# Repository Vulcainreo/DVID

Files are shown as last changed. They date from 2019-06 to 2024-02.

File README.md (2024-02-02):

# DVID
Damn Vulnerable IoT Device - The first opensource vulnerable designed IoT device

**⚠️ This project is currently in development ⚠️**

All details are available on DVID website : [http://dvid.eu](http://dvid.eu)

# Project overview

This IoT device is designed by my own and published on OpenSource. The main objective is to provide to each interrested people a vulnerable board to improve their skill in IoT hacking.

The board core is composed by a Atmega328p and a OLED screen. For each vulnerabilities, a firmware could be flashed on the Atmega328p in order to offer a specific vulnerable environment.

There is also connection port like UART, Bluetooth, 2,4Ghz and Wifi. In each vulnerability, a specific extension board must be plugged to the board.

Hacking required attacks tools like USBasp and USBuart.

# Board

You can buy the board on marketplace (available soon) or build it yourself with Gerber files.
The board is shipped with theses three packages :
* **Board only and component reference** : Naked board only. You must buy all component yourself and solder all component.
* **Soldered board without attack component and extention** : Soldered board but you must buy all external tools like USBuart, USBasp, extention board.
* **Full package** : Everything needed (soldered board, external board and attack tools).

# Contribution

If you want to contribute to the project, don't hesitate to open a pull request.
By the way, about firmware compilation, you need to compile for atmega328p breadboard 8mhz.
In order to do that, just add this board to the /arduino/hardware/arduino/avr/board.txt file

```bash
##############################################################

atmega328bb.name=ATmega328 on a breadboard (8 MHz internal clock)

atmega328bb.upload.protocol=arduino
atmega328bb.upload.maximum_size=30720
atmega328bb.upload.speed=57600

atmega328bb.bootloader.low_fuses=0xE2
atmega328bb.bootloader.high_fuses=0xDA
atmega328bb.bootloader.extended_fuses=0x05

atmega328bb.bootloader.file=atmega/ATmegaBOOT_168_atmega328_pro_8MHz.hex
atmega328bb.bootloader.unlock_bits=0x3F
atmega328bb.bootloader.lock_bits=0x0F

atmega328bb.build.mcu=atmega328p
atmega328bb.build.f_cpu=8000000L
atmega328bb.build.core=arduino:arduino
atmega328bb.build.variant=arduino:standard

atmega328bb.bootloader.tool=arduino:avrdude
atmega328bb.upload.tool=arduino:avrdude
```

In order to upload, select "USBAsp" in `Tool -> Programmer` and start the upload using `Sketch -> Upload Using Programmer`

# Write-ups

Many thanks to [@ghozt](https://twitter.com/ghozt), [@shoxxdj](https://twitter.com/shoxxdj) and [@podalirius](https://twitter.com/podalirius)

## In french 🇫🇷

### Hardware

* Find The Datasheet - [https://shoxxdj.fr/dvid-hardware-find-the-datasheet/](https://shoxxdj.fr/dvid-hardware-find-the-datasheet/)
* Find The Datasheet - [https://podalirius.net/fr/writeups/dvid-writeup-01-hardware-find-the-datasheet/](https://podalirius.net/fr/writeups/dvid-writeup-01-hardware-find-the-datasheet/)

### Firmware

* Default Password - [https://shoxxdj.fr/dvid-firmware-defaultpassword/](https://shoxxdj.fr/dvid-firmware-defaultpassword/)
* Default Password - [https://podalirius.net/fr/writeups/dvid-writeup-03-firmware-default-password/](https://podalirius.net/fr/writeups/dvid-writeup-03-firmware-default-password/)

### Bluetooth

* Advertising - [https://podalirius.net/fr/writeups/dvid-writeup-04-bluetooth-advertise/](https://podalirius.net/fr/writeups/dvid-writeup-04-bluetooth-advertise/)
* Characteristics - [https://podalirius.net/fr/writeups/dvid-writeup-05-bluetooth-characteristics/](https://podalirius.net/fr/writeups/dvid-writeup-05-bluetooth-characteristics/)
* Characteristics2 - [https://podalirius.net/fr/writeups/dvid-writeup-06-bluetooth-characteristics2/](https://podalirius.net/fr/writeups/dvid-writeup-06-bluetooth-characteristics2/)

## In english 🇬🇧

### Hardware

* Find The Datasheet - [https://podalirius.net/en/writeups/dvid-writeup-01-hardware-find-the-datasheet/](https://podalirius.net/en/writeups/dvid-writeup-01-hardware-find-the-datasheet)

### Firmware

* Hardcoded Password - [https://podalirius.net/en/writeups/dvid-writeup-02-firmware-hardcoded-password/](https://podalirius.net/en/writeups/dvid-writeup-02-firmware-hardcoded-password/)
* Default Password - [https://podalirius.net/en/writeups/dvid-writeup-03-firmware-default-password/](https://podalirius.net/en/writeups/dvid-writeup-03-firmware-default-password/)

### Bluetooth

* Advertising - [https://podalirius.net/en/writeups/dvid-writeup-04-bluetooth-advertise/](https://podalirius.net/en/writeups/dvid-writeup-04-bluetooth-advertise/)
* Characteristics - [https://podalirius.net/en/writeups/dvid-writeup-05-bluetooth-characteristics/](https://podalirius.net/en/writeups/dvid-writeup-05-bluetooth-characteristics/)
* Characteristics2 - [https://podalirius.net/en/writeups/dvid-writeup-06-bluetooth-characteristics2/](https://podalirius.net/en/writeups/dvid-writeup-06-bluetooth-characteristics2/)

# Part list

Part | Quantity | Total Cost | Buying link
--- | --- | --- | ---
Board | 1 | 3€ | Available soon or build yourself :)
Jumper Double Row Female 2x4P | 2 | 1€ | https://www.banggood.com/30pcs-2_54mm-2x4P-8P-Double-Row-Female-Straight-Pin-Header-Needle-Socket-Pin-Strip-p-1348262.html
Jumper Single Row Male | 4 | 1€ | https://www.banggood.com/10Pcs-40-Pin-2_54mm-Male-Female-SIL-Socket-Row-Strip-PCB-Connector-p-953436.html
28 pins socket (for atmega328p) | 1 | 0,5€ | https://www.banggood.com/50pcs-28-Pins-IC-DIP-2_54mm-Wide-Integrated-Circuit-Sockets-Adaptor-p-1211042.html
Oled Screen 4Pin white | 1 | 5€ | https://www.banggood.com/1_3-Inch-4Pin-White-OLED-LCD-Display-12864-IIC-I2C-Interface-Module-For-Arduino-p-1067874.html
Atmega328p | 1 | 3€ | https://www.banggood.com/DIP28-ATmega328PPU-MCU-IC-Chip-With-Arduino-UNO-Bootloader-p-932159.html
5V to 3V power supply | 1 | 1€ | https://www.banggood.com/5V-To-3_3V-DC-DC-Step-Down-Power-Supply-Buck-Module-AMS1117-800MA-p-933674.html
Status led | 1 | 0,5€ | https://www.banggood.com/10pcs-5mm-3000-6000mcd-LED-Bright-Decoration-Torch-Toy-Light-Green-p-73175.html
Total |  | 15€ |

# Attack tools and extention board

Part | Quantity | Total Cost | Buying link
--- | --- | --- | ---
UsbUART | 1 | 3€ |  https://www.banggood.com/CP2102-USB-To-TTL-Module-p-1263924.html
UsbASP adapter | 1 | 4€ | https://www.banggood.com/3_3V-5V-USBASP-USBISP-AVR-Programmer-Downloader-ATMEGA8-ATMEGA128-With-Download-Cable-p-1179967.html
AT-09 BLE module | 1 | 2€ | https://www.banggood.com/AT-09-4_0-BLE-Wireless-bluetooth-Module-Serial-Port-CC2541-Compatible-HM-10-Module-Connecting-Single-Chip-Microcomputer-p-1455191.html
CSR BLE adapter | 1 | 4€ | https://www.banggood.com/Mini-Wireless-Dongle-CSR-4_0-Bluetooth-Adapter-V4_0-USB-2_03_0-For-Win-7810XP-For-Vista-3264-p-1132661.html
Jumper Wire female female | 1 | 2€ | https://www.banggood.com/120pcs-20cm-Male-To-Female-Female-To-Female-Male-To-Male-Color-Breadboard-Jumper-Cable-Dupont-Wire-Combination-For-Arduino-p-974006.html
ESP8266 | 1 | 2€ | https://www.banggood.com/Upgraded-Version-1M-Flash-ESP8266-ESP-01-WIFI-Transceiver-Wireless-Module-p-979509.html
Total |  | 17€ |

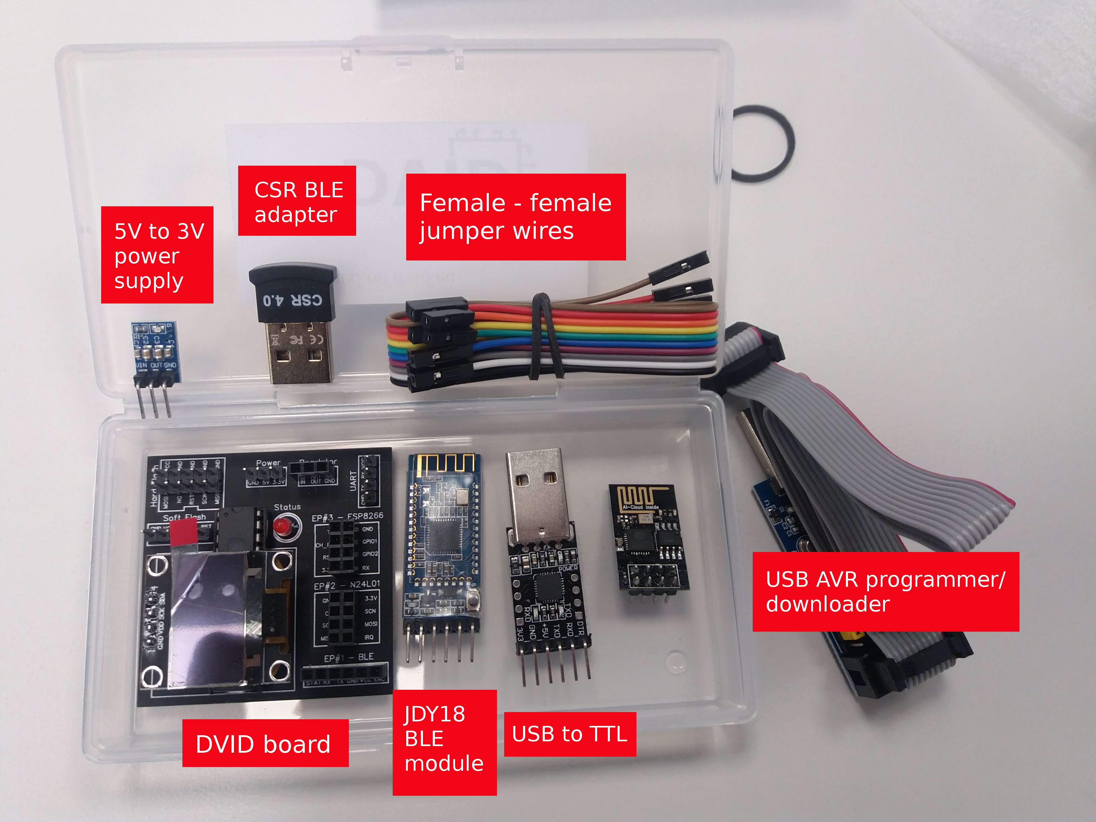
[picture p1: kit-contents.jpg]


# Troubleshooting

In case of frying your board, you may encounter some issue with new version of chinese component. This part is dedicated to allow you to start to discuss with your component and put it in the ready-to-hack configuration

## Bluetooth AT-09

Last received parcel contains a new version of the AT-09, named MLT-BT05. This new version natively discuss over UART with 115200 baudrate.
The DVID can discuss to peripherial with 9600 baudrate.
In order to change that, follow those steps:
* Connect your AT-09 to your uart dongle : RX>TX, TX>RX, VCC>VCC and Gnd>Gnd
* Open a serial monitor and type : AT+BAUD4
* If you receive "OK", your BLE peripherial is ready-to-hack

## Atmega328p

Last received parcel contains a new version of Atmega328p. This version seems to be virgin and allow communication with very slow SCK.
In order to modify the internal configuration (fuse), follow those steps:
* Solder (or shortcut) the Jumper #3 on the USBasp flashing dongle
* Type this command to be sure that you can communicates with the broken Atmega328p : `avrdude -v -patmega328p -cusbasp`
* If you receive "hfuse reads D9" and "lfuse reads FF", your device is already ready-to-hack
* If not, type this command : `avrdude -v -patmega328p -U lfuse:w:0xE2:m -cusbasp`
* You can type again `avrdude -v -patmega328p -cusbasp` to be sure that fuse configuration changed

You can not unsolder or remove shortcut on the Jumper #3. If you don't remove it, flashing process will take 20 more times.
You can now flash all firmware on you DVID !

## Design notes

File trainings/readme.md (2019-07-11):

Here, you will find some training with DVID board.
Please, don't share flags in public.

Have fun :)

# Trainers

You need to flash the firmware on the board.

- Plug USBasp on the board (hard flash zone)
- Plug in any other extension needed for the training e.g the JDY-18 BLE module

Then, flash with `avrdude`:

`avrdude -c usbasp -p m328p -C pathto/avrdude.conf -U flash:w:pathtofirmware.hex`

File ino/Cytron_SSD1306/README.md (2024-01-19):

# Lightweight-I2C-SSD1306

Lightweight I2C SSD1306 Arduino Library for displaying text and simple bitmap images.</br>

<b>Dependencies:</b>
<ul>
<li><a href="https://github.com/greiman/SSD1306Ascii" target=_blank><b>SSD1306Ascii</b> by Greiman</a></li>
</ul>

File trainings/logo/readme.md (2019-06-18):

The following post describes how to use the DVID screen to write text on it 
or to draw pictures on it.

## Arduino IDE and libraries

### IDE
First things first, we will need the Arduino IDE installed.
When this is done we will need to select the proper programmer in 
`Tools > Programmer`. Since we use a USBAsp to program the Atmega328p, we
select **USBAsp**.

### Libraries
Now we will need to install the Adafruit libraries.
To do so, we navigate in **Tools > Manage libraries**.
Then we search for **adafruit SSD1306** and install Adafruit SSD1306.
We then search **adafruit GFX** and install Adafruit GFX Library.

We now have everything needed to start playing with the screen.

## Example sketch

Adafruit provides [examples](https://github.com/adafruit/Adafruit_SSD1306/tree/master/examples) of how to use their library.

We have the choice between four scripts :
- ssd1306_128x32_i2c 	
- ssd1306_128x32_spi 	
- ssd1306_128x64_i2c 	
- ssd1306_128x64_spi

The [OLED screen used by DVID](https://www.banggood.com/1_3-Inch-4Pin-White-OLED-LCD-Display-12864-IIC-I2C-Interface-Module-For-Arduino-p-1067874.html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) has the following characteristics :

- Resolution: 128*64
- Control chip: SSH1106
- Display area: 29.42 x 14.7mm
- Driving voltage: 3.3-5V
- Operating temperature: -40 ℃ to 70 ℃
- Interface type: IIC/I2C  interface

According to our screen characteristics, we use the script `ssd1306_128x64_i2c`.
We copy it in our arduino IDE, and start a compilation (Sketch > Verify/Compile).

Then we upload the sketch to the board with **Sketch > Upload using programmer**.

And ... tada ! *Nothing happens*.

Why is that ?

## I2C address

After [some research](https://startingelectronics.org/tutorials/arduino/modules/OLED-128x64-I2C-display/) we find that the problem lies in this line :
~~~c
 if(!display.begin(SSD1306_SWITCHCAPVCC, 0x3D)) { // Address 0x3D for 128x64
~~~

This bit of code leads us to believe that the parameter `0x3D` is linked to 
the resolution of the screen, but it is not. Actually if we replace `0x3D` 
by `0x3C` as suggested in the blog post linked above, our example will work 
perfectly (in my case, at least).

If we look at the [source code](https://github.com/adafruit/Adafruit_SSD1306/blob/master/Adafruit_SSD1306.cpp) of the Adafruit library we see that the prototype
for the `begin` function is :

~~~c
boolean Adafruit_SSD1306::begin(uint8_t vcs, uint8_t addr, boolean reset,
boolean periphBegin)
~~~

The documentation specifies that 
> @param  addr
       I2C address of corresponding SSD1306 display (or pass 0 to use
       default of 0x3C for 128x32 display, 0x3D for all others).
       SPI displays (hardware or software) do not use addresses, but
       this argument is still required (pass 0 or any value really,
       it will simply be ignored). Default if unspecified is 0.

So `0x3D` is supposed to be the I2C address of the `SSD1306` display.
The issue is the `0x3D` does not seem to be the address of our display.

So how do we find the I2C ? Some quick `DDG` search gives us the tool
[I2cScanner](https://playground.arduino.cc/Main/I2cScanner/
).

So we just have to copy the script into our Arduino IDE and upload it with the 
USBAsp programmer.

Then we use a serial connection to connect to the board and we will get the 
information we are looking for :

~~~bash
cu -l /dev/ttyUSB0 -s 9600
Connected.
Scanning...
I2C device found at address 0x3C  !
done
~~~

Now if we replace the `0x3D` address by the one displayed we will have a working
demo.

## About I2C

We've been talking about I2C but what is it exactly ?

The Inter-integrated Circuit (I2C) Protocol is a protocol intended to allow 
multiple "slave" digital integrated circuits ("chips") to communicate with one 
or more "master" chips. Like the Serial Peripheral Interface (SPI), it is only 
intended for short distance communications within a single device. 
Like Asynchronous Serial Interfaces (such as RS-232 or UARTs), it only requires 
two signal wires to exchange information.

A full introduction can be found on [sparkfun.com](https://learn.sparkfun.com/tutorials/i2c/all).

## Drawing a bitmap

Now that we've seen how to make the example sketch work, let's do one of our 
own.
In this sketch we will attempt to draw a logo from a bitmap.

First we create a logo in Gimp. To do this we create a new project for 
a `128x64` pixels image and we do some pixel art with a hardbrush pencil with 
a size of 1 pixel.

Once this is done we export the logo as a `*.xbm` file.
We then rename the file as `*.c` and open it in an editor.
We retrieve the array and paste it in our sketch.
We just have to [modify the type](https://github.com/adafruit/Adafruit-GFX-Library/pull/31) to `static const uint8_t PROGMEM` then we can use it in our code.

To use it we just have to call `drawXBitmap` and give it our bitmap to display
it.

~~~c
#include <SPI.h>
#include <Wire.h>
#include <Adafruit_GFX.h>
#include <Adafruit_SSD1306.h>
#include <Fonts/FreeSans9pt7b.h>

#define DVID_logo_width 128
#define DVID_logo_height 64

#define SCREEN_WIDTH 128 // OLED display width, in pixels
#define SCREEN_HEIGHT 64 // OLED display height, in pixels

// Declaration for an SSD1306 display connected to I2C (SDA, SCL pins)
#define OLED_RESET     -1 // Reset pin # (or -1 if sharing Arduino reset pin)
Adafruit_SSD1306 display(SCREEN_WIDTH, SCREEN_HEIGHT, &Wire, OLED_RESET);

static const uint8_t PROGMEM DVID_logo_bits[] = {
   0x00, 0x00, 0x00, 0x00, 0x00, 0x00, 0x00, 0x00, 0x00, 0x00, 0x00, 0x00,
   0x00, 0x00, 0x00, 0x00, 0x00, 0x00, 0x00, 0x00, 0x00, 0x00, 0x00, 0x00,
   0x00, 0x1c, 0xfe, 0xff, 0x01, 0x00, 0x00, 0x00, 0x00, 0x00, 0x00, 0x00,
   0x00, 0x00, 0x00, 0x00, 0x00, 0x14, 0x02, 0x00, 0x01, 0x80, 0x03, 0x00,
   0x00, 0x00, 0x00, 0x00, 0x00, 0x00, 0x00, 0x00, 0x00, 0x1c, 0xf2, 0x1f,
   0xff, 0xff, 0x02, 0x00, 0x00, 0x00, 0x00, 0x00, 0x00, 0x00, 0x00, 0x00,
   0x00, 0x08, 0x12, 0x10, 0x00, 0x9c, 0x03, 0x00, 0x00, 0x00, 0x00, 0x00,
   0x00, 0x00, 0x00, 0x00, 0x00, 0x08, 0x12, 0xf0, 0xff, 0x17, 0x00, 0x00,
   0x00, 0x00, 0x00, 0x00, 0x00, 0x00, 0x00, 0x00, 0x00, 0x08, 0x12, 0x00,
   0x00, 0x1c, 0x00, 0x00, 0x00, 0x00, 0x00, 0x00, 0x00, 0x00, 0x00, 0x00,
   0x00, 0x08, 0x12, 0x00, 0x00, 0x00, 0x00, 0x00, 0x00, 0x00, 0x00, 0x00,
   0x00, 0x00, 0x00, 0x00, 0xe0, 0xff, 0xff, 0xff, 0xff, 0x7f, 0x00, 0x00,
   0x00, 0x00, 0x00, 0x00, 0x00, 0x00, 0x00, 0x00, 0x20, 0x00, 0x00, 0x00,
   0x00, 0x40, 0x00, 0x00, 0x00, 0x00, 0x00, 0x00, 0x00, 0x00, 0x00, 0x00,
   0x20, 0x00, 0x00, 0x00, 0x00, 0x40, 0x00, 0x00, 0x00, 0x00, 0x00, 0x00,
   0x00, 0x00, 0x00, 0x00, 0x20, 0x00, 0x00, 0x00, 0x00, 0x40, 0x00, 0x00,
   0x00, 0x00, 0x00, 0x00, 0x00, 0x00, 0x00, 0x00, 0x20, 0x00, 0x00, 0x00,
   0x00, 0x40, 0x00, 0x00, 0x00, 0x00, 0x00, 0x00, 0x00, 0x00, 0x00, 0x00,
   0x20, 0x00, 0x00, 0x00, 0x00, 0x40, 0x00, 0x00, 0x00, 0x00, 0x00, 0x00,
   0x00, 0x00, 0x00, 0x00, 0x20, 0x00, 0x00, 0x00, 0x00, 0xc0, 0xff, 0x07,
   0x00, 0x00, 0x00, 0x00, 0x00, 0x00, 0x00, 0x00, 0x00, 0x00, 0x00, 0x00,
   0x00, 0x40, 0x00, 0x04, 0x00, 0x00, 0x00, 0x00, 0x00, 0x00, 0x00, 0x00,
   0x00, 0x00, 0x00, 0x00, 0x00, 0x40, 0x00, 0x04, 0x00, 0xff, 0x3f, 0x00,
   0xf8, 0x00, 0x00, 0x3e, 0x78, 0x80, 0xff, 0x0f, 0x00, 0xc0, 0x7f, 0x04,
   0x00, 0xff, 0xff, 0x00, 0xf8, 0x00, 0x00, 0x3e, 0x78, 0x80, 0xff, 0x3f,
   0x00, 0x40, 0x40, 0x04, 0x00, 0xff, 0xff, 0x03, 0xf8, 0x01, 0x00, 0x3f,
   0x78, 0x80, 0xff, 0xff, 0x00, 0x40, 0x40, 0x04, 0x00, 0xff, 0xff, 0x07,
   0xf8, 0x01, 0x00, 0x1f, 0x78, 0x80, 0x07, 0xf8, 0x01, 0x40, 0x40, 0x04,
   0x00, 0x0f, 0xf0, 0x0f, 0xf0, 0x01, 0x00, 0x1f, 0x78, 0x80, 0x07, 0xe0,
   0x03, 0x40, 0x40, 0x04, 0x00, 0x0f, 0xc0, 0x1f, 0xf0, 0x03, 0x80, 0x0f,
   0x78, 0x80, 0x07, 0xc0, 0x07, 0x40, 0x40, 0x04, 0x00, 0x0f, 0x80, 0x1f,
   0xe0, 0x03, 0x80, 0x0f, 0x78, 0x80, 0x07, 0x80, 0x07, 0x40, 0x40, 0x04,
   0x00, 0x0f, 0x00, 0x3f, 0xe0, 0x03, 0x80, 0x0f, 0x78, 0x80, 0x07, 0x00,
   0x0f, 0x40, 0x40, 0x04, 0x00, 0x0f, 0x00, 0x3e, 0xe0, 0x07, 0xc0, 0x07,
   0x78, 0x80, 0x07, 0x00, 0x0e, 0x40, 0xe0, 0x04, 0x00, 0x0f, 0x00, 0x3e,
   0xc0, 0x07, 0xc0, 0x07, 0x78, 0x80, 0x07, 0x00, 0x1e, 0x40, 0xa0, 0x04,
   0x00, 0x0f, 0x00, 0x7c, 0xc0, 0x07, 0xc0, 0x07, 0x78, 0x80, 0x07, 0x00,
   0x1c, 0x40, 0xe0, 0x04, 0x00, 0x0f, 0x00, 0x7c, 0xc0, 0x0f, 0xe0, 0x03,
   0x78, 0x80, 0x07, 0x00, 0x1c, 0x40, 0x00, 0x04, 0x00, 0x0f, 0x00, 0x7c,
   0x80, 0x0f, 0xe0, 0x03, 0x78, 0x80, 0x07, 0x00, 0x1c, 0x40, 0x00, 0x04,
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
   
void setup()   
{
    Serial.begin(9600);

  // SSD1306_SWITCHCAPVCC = generate display voltage from 3.3V internally
  if(!display.begin(SSD1306_SWITCHCAPVCC, 0x3C)) {
    Serial.println(F("SSD1306 allocation failed"));
    for(;;); // Don't proceed, loop forever
  }
  display.clearDisplay();
  display.drawXBitmap(0, 0, DVID_logo_bits, DVID_logo_width, DVID_logo_height, 1);
  display.display(); 
}

void loop() {}
~~~

And it works !

## Adding some animation

Now how about we add some animation to our logo ?
You can find an example firmware in `trainings/Logo/dvid_logo.ino`.

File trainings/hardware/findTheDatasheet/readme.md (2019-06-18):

# Find the datasheet training
## Goal
A password is displayed on the pin PD1

## Guidelines
The DVID board contains a microcontroller
* Find the datasheet on Internet to identify the PD1
* Find PD1 pin correspondance on DVID (ex.: github)
* Connect a UART RX to PD1 to get the password

## Result
The password is a l33t string

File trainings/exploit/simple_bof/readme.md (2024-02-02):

# Simple Buffer Overflow
## Goal
Your goal is to have the string "Well done!" displayed on the sreen

## Tips
If you need to send bytes that are not printable, you can use the `pyserial` python library.

The architecture of the Atmega328p is little endian, you might need to know what it means

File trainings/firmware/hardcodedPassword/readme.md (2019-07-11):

# Hardcoded password training
## Goal
A confidential message is stored on the firmware but protected by a password.

## Guidelines
* Extract the firmware
* Locate the password
* Write the password over the UART connection
* Get the flag

NB : Nothing will be printed on the serial (just RX is configured)

## Result
The flag is an animal's name.

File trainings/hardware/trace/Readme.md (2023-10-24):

# Trace
This training aims to teach hardware registry and AVR simulation.

## Setup
* Flash the firmware on your DVID [download](./registry.hex)

```bash
avrdude -v -pm328 -cusbasp -u -U flash:w:registry.hex -F
```

* Install simavr tool
```bash
sudo apt install freeglut3-dev libglfw3-dev libgl1-mesa-dev libglu1-mesa-dev avr-libc gcc-avr libelf-dev

git clone https://github.com/buserror/simavr
cd simavr
make
sudo make install release=1
```

## Instruction
Something is written on eeprom. You need to explore the firmware to discovery what. You can try to run the firmware on the DVID or try an alternative way.

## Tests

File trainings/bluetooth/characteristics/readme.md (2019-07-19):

# Bluetooth - characteristic
## Goal
* One time password bluetooth device
* Works with an android application, but you don't have it
* The goal is to provide a screenshot of the password

## Tips
Verbose mode = 1 on 0000ffe1

## Result
The password is an animal name.

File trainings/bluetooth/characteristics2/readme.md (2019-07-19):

# Bluetooth - characteristic2
## Goal
* A confidential message is stored on the firmware but protected by a password
* The goal is to provide a screenshot of the confidential message

## Tips
Come on to say hello on 0000ffe1

## Result
The password is an animal name.

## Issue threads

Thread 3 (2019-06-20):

Board generates garbage input

cryptax, 2019-06-20:
I get this issue frequently, but not always, on several different trainings. The board receives **garbage input**, and consequently *does not validate the input.*

**Example #1 . BLE characteristics training**
I boot/power the board. It prints the message asking to send `abcd`. I haven't sent anything yet, haven't even connected to the board that it has already apparently received garbage data (e.g `AME=D\nVID-TAA` -- an overflow somewhere?) and prints this as the incoming pass. When I send `abcd`, it does not validate it, because it apparently receives something else. Note that I have validated the challenge in other cases.
Note this example does not use UART.

**Example #2. Default password**
I boot/power the board. It asks for a password. I send it via UART 9600 bauds. It says the password is incorrect (actually, it is correct, but nevermind at this step, the issue is rather that it does not receive it correctly) but does not print correctly what I have sent. Random ASCII chars garbage instead.
In case the USB to TTL is faulty, I have tested with another one. Same problem.

I have been told such issues could be related to bad ground or VCC connections on the board, but to be honest, I have no idea what's happening.

Vulcainreo, 2019-06-20:
Hello,
Thank you for feedback. Have you tried to power the DVID from uart only ? Also, is you connect the power first and RX / TX next, garbage vanish.
This issue is already known (rare condition) and a fix a on the way.

cryptax, 2019-06-21:
>Have you tried to power the DVID from uart only ?

Yes, several times. Same issue.

> Are you connect the power first and RX / TX next ?

Tried this. But no change.

Vulcainreo, 2024-01-26:
Hello,
No possibility to reproduce the bug in lab. Please, re-open if needed.

Closed 2024-01-26.

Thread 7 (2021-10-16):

documentation minor changes are required for dvid writeup 01 instructions

thomasgarai, 2021-10-16:
For linux users reading these instructions ( https://podalirius.net/en/writeups/dvid-writeup-01-hardware-find-the-datasheet/ ) some additional info should be provided as follows:

Step 1: Assemble and connect DVID device to USB port.

Step 2: Find the bus and device id using the following command:
**lsusb**

Step 3: Look for this line in the output of lsusb command to get device and bus id:
**_Bus 002 Device 012: ID 16c0:05dc Van Ooijen Technische Informatica shared ID for use with libusb_**

Step 4: create access to this device using the following command:
**sudo chmod a+w /dev/bus/usb/002/012**

Step 5: flash the EEPROM using the following command:
**avrdude -F -v -patmega328p -P/dev/bus/usb/002/012 -cusbasp -u -U flash:w:findTheDatasheet.ino.arduino_standard.hex**

tail of sample output below:
=====================
Writing | ################################################## | 100% 7.30s

avrdude: 14346 bytes of flash written
avrdude: verifying flash memory against findTheDatasheet.ino.arduino_standard.hex:
avrdude: load data flash data from input file findTheDatasheet.ino.arduino_standard.hex:
avrdude: input file findTheDatasheet.ino.arduino_standard.hex auto detected as Intel Hex
avrdude: input file findTheDatasheet.ino.arduino_standard.hex contains 14346 bytes
avrdude: reading on-chip flash data:

Reading | ################################################## | 100% 3.72s

avrdude: verifying ...
avrdude: 14346 bytes of flash verified

avrdude done.  Thank you.

Vulcainreo, 2021-12-16:
Hello,
Thank you for details. I plan to add those elements in Wiki of the project for troubleshooting.
I will close the issue.

Closed 2021-12-16.

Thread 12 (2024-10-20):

Can't clone repo: This repository is over its data quota. Account responsible for LFS bandwidth should purchase more data packs to restore access.

parsley72, 2024-10-20:
If I try to clone this repo I get:
```
$ git clone https://github.com/Vulcainreo/DVID.git
Cloning into 'DVID'...
remote: Enumerating objects: 2570, done.
remote: Counting objects: 100% (625/625), done.
remote: Compressing objects: 100% (396/396), done.
remote: Total 2570 (delta 188), reused 618 (delta 183), pack-reused 1945 (from 1)
Receiving objects: 100% (2570/2570), 14.74 MiB | 2.52 MiB/s, done.
Resolving deltas: 100% (373/373), done.
Downloading ino/arduino-1.8.16.tar.xz (130 MB)
Error downloading object: ino/arduino-1.8.16.tar.xz (54af929): Smudge error: Error downloading ino/arduino-1.8.16.tar.xz (54af92925db18ea3d660410ab750822f0059471a3245f610dffeb40727a7f69a): batch response: This repository is over its data quota. Account responsible for LFS bandwidth should purchase more data packs to restore access.

Errors logged to '/home/tom/Documents/GitHub-personal/DVID/.git/lfs/logs/20241020T130939.208390503.log'.
Use `git lfs logs last` to view the log.
error: external filter 'git-lfs filter-process' failed
fatal: ino/arduino-1.8.16.tar.xz: smudge filter lfs failed
warning: Clone succeeded, but checkout failed.
You can inspect what was checked out with 'git status'
and retry with 'git restore --source=HEAD :/'
```
My data quote is fine (check "Git LFS Data" on https://github.com/settings/billing/summary). Have you enabled Git LFS on this repo? See https://stackoverflow.com/a/74868040/264822

parsley72, 2024-10-27:
This is working now, don't know if it was a temporary Github glitch.

Vulcainreo, 2024-10-27:
Hello,
Thank you for notification related to LFS. I use that functionality to host arduino files in order to build the docker image dvid-ino.

Closed 2024-10-27.

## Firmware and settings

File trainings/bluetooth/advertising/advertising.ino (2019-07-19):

#include <SPI.h>
#include <Wire.h>
#include <Adafruit_GFX.h>
#include <Adafruit_SSD1306.h>
#include <Fonts/FreeSans9pt7b.h>
#include <SoftwareSerial.h>


Adafruit_SSD1306 display(-1);
String message = "D5uzzcrz4kf23fk";
String currentPassword = "";
bool finished = false;
String rx = "";
bool first = true;
String bluetoothName = "";
int name = 0;
SoftwareSerial ble(7,6);


void printScreen(String text, String progress) {

  // Clear the buffer.
  display.clearDisplay();

  display.setCursor(0,0);
  //               xxxxxxxxxxxxxxxxx"+progress+"x
  display.println("T1-ADVERTISING   "+progress+"%"); //first line - only 21 chars
  display.drawLine(0,7,120,7,WHITE);

  display.setCursor(0,8);
  display.println(text);

  display.display();
}

void setup()
{
  // initialize with the I2C addr 0x3C
  display.begin(SSD1306_SWITCHCAPVCC, 0x3C);
  currentPassword = "";

 // Display Text
  display.clearDisplay();

  display.setTextSize(1);      // Normal 1:1 pixel scale
  display.setTextColor(WHITE); // Draw white text
  display.cp437(true);         // Use full 256 char 'Code Page 437' font

  // BLE
  ble.begin(9600);

  delay(1000);
  int name = random(1000);
  bluetoothName = "dvid-"+String(name);


  ble.println("AT+IBEA0");
  ble.println("AT+ROLE0");
  ble.println("AT+UUID0xFFE0");
  ble.println("AT+CHAR0xFFE1");
  ble.println("AT+NAME"+bluetoothName);
  ble.println("AT+RESET");

  Serial.begin(9600);
  while (!Serial) {
    ; // wait for serial port to connect. Needed for native USB port only
  }

  currentPassword = "";

  display.begin(SSD1306_SWITCHCAPVCC, 0x3C);

 // Display Text
  display.clearDisplay();

  display.setTextSize(1);      // Normal 1:1 pixel scale
  display.setTextColor(WHITE); // Draw white text
  display.cp437(true);         // Use full 256 char 'Code Page 437' font

  String m = String(message[0])+String(message[2])+String(message[5])+String(message[9]);
  printScreen("I have confidential message. Pass ?", "  0");

  while(!finished) {

    if (currentPassword != bluetoothName) {

      if (!first) {
        printScreen("Wrong password\nTry again", " 50");
        currentPassword = "";
      }

      if (Serial.available() > 0) {

        rx = Serial.readString();
        currentPassword = currentPassword + rx;
        currentPassword.trim();
        printScreen("Pass : "+currentPassword, " 50");
        first = false;
        delay(2000);
      }
    }
    else
    {
      printScreen("Well done! Message : "+m,"100");
      finished = true;
    }


  }
}

void loop() { }

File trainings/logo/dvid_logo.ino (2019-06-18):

/**************************************************************************
This firmware displays a DVID logo in a slick animation.
 **************************************************************************/

#include <SPI.h>
#include <Wire.h>
#include <Adafruit_GFX.h>
#include <Adafruit_SSD1306.h>

#define SCREEN_WIDTH 128 // OLED display width, in pixels
#define SCREEN_HEIGHT 64 // OLED display height, in pixels

// Declaration for an SSD1306 display connected to I2C (SDA, SCL pins)
#define OLED_RESET     -1 // Reset pin # (or -1 if sharing Arduino reset pin)
Adafruit_SSD1306 display(SCREEN_WIDTH, SCREEN_HEIGHT, &Wire, OLED_RESET);

#define DVID_circuit_width 51
#define DVID_circuit_height 55
static const uint8_t PROGMEM DVID_circuit_bits[] = {
   0xf0, 0x01, 0x00, 0x00, 0x00, 0x00, 0x00, 0x08, 0x02, 0x00, 0x00, 0x00,
   0x00, 0x00, 0x04, 0x04, 0x00, 0x00, 0x00, 0x00, 0x00, 0xe2, 0x08, 0x00,
   0x00, 0x00, 0x00, 0x00, 0x10, 0x01, 0x00, 0x00, 0x00, 0x00, 0x00, 0x40,
   0x00, 0x00, 0x00, 0x00, 0x00, 0x07, 0xe0, 0x00, 0x00, 0x00, 0x00, 0x00,
   0x05, 0xff, 0xff, 0xff, 0xff, 0xff, 0x80, 0x07, 0x01, 0x00, 0x00, 0x00,
   0x80, 0xc0, 0x00, 0x01, 0x00, 0x00, 0x33, 0xb3, 0x60, 0x00, 0x01, 0x00,
   0x00, 0x33, 0xb3, 0x31, 0x00, 0x01, 0x00, 0x00, 0x00, 0x80, 0x1f, 0x00,
   0x00, 0x00, 0x00, 0x00, 0x80, 0x01, 0x00, 0x00, 0x00, 0x00, 0x00, 0x80,
   0x00, 0x00, 0x00, 0x00, 0x00, 0x00, 0x80, 0x00, 0x00, 0x00, 0x00, 0x00,
   0x00, 0x80, 0x00, 0x00, 0x00, 0x00, 0x00, 0x00, 0x80, 0x31, 0x07, 0x42,
   0x00, 0x00, 0x00, 0x80, 0xff, 0x05, 0x42, 0x00, 0x00, 0x00, 0x80, 0x31,
   0x07, 0x00, 0x00, 0x00, 0x00, 0x80, 0x30, 0x00, 0x00, 0x00, 0x00, 0x00,
   0x80, 0x30, 0x00, 0x42, 0x00, 0x00, 0x00, 0x80, 0x30, 0x00, 0x42, 0x00,
   0x00, 0x00, 0x80, 0x31, 0x07, 0x00, 0x00, 0x00, 0x00, 0x80, 0xff, 0x05,
   0x00, 0x00, 0x00, 0x00, 0x80, 0x31, 0x07, 0x42, 0x00, 0x00, 0x00, 0x80,
   0x00, 0x00, 0x42, 0x00, 0x00, 0x00, 0x80, 0x00, 0x00, 0x00, 0x00, 0x00,
   0x00, 0x80, 0x00, 0x00, 0x00, 0x00, 0x00, 0x00, 0x80, 0x01, 0x00, 0x42,
   0x00, 0x00, 0x00, 0x80, 0x1f, 0x00, 0x42, 0x00, 0x00, 0x00, 0x80, 0x11,
   0x00, 0x00, 0x00, 0x00, 0x00, 0x80, 0x10, 0x00, 0x00, 0x00, 0x00, 0x00,
   0x80, 0x10, 0x00, 0x42, 0x00, 0x00, 0x00, 0x80, 0x10, 0x00, 0x42, 0x00,
   0x00, 0x00, 0x80, 0x10, 0x00, 0x00, 0x00, 0x00, 0x00, 0x80, 0x10, 0x00,
   0x00, 0x00, 0x00, 0x00, 0x80, 0x10, 0x00, 0x42, 0x00, 0x00, 0x00, 0x80,
   0x10, 0x00, 0x42, 0x00, 0x00, 0x00, 0x80, 0x38, 0x00, 0x00, 0x00, 0x00,
   0x00, 0x80, 0x28, 0x00, 0x00, 0x00, 0x00, 0x00, 0x80, 0x38, 0x00, 0x42,
   0x00, 0x00, 0x00, 0x80, 0x00, 0x00, 0x42, 0x00, 0x00, 0x00, 0x80, 0x00,
   0x00, 0x00, 0x00, 0x00, 0xe0, 0xb8, 0x00, 0x00, 0x00, 0x00, 0x00, 0xa0,
   0xa8, 0x00, 0x00, 0x00, 0x00, 0x00, 0xf0, 0xb8, 0x00, 0x00, 0x00, 0x00,
   0x00, 0x18, 0x8c, 0x00, 0x00, 0x00, 0x00, 0x00, 0x0c, 0x86, 0x00, 0x00,
   0x01, 0x00, 0x00, 0x06, 0x83, 0x00, 0x00, 0x01, 0x00, 0x00, 0x83, 0x81,
   0x00, 0x00, 0x01, 0x00, 0x80, 0xc1, 0x80, 0x00, 0x00, 0x01, 0x00, 0xc0,
   0x60, 0x80, 0x00, 0x00, 0xff, 0xff, 0xff, 0xff, 0xff, 0x00, 0x00, 0x30,
   0x33, 0x03, 0x00, 0x00, 0x00, 0x00, 0x30, 0x33, 0x03, 0x00, 0x00, 0x00,
   0x00 };
   
void setup() {
  Serial.begin(9600);

  // SSD1306_SWITCHCAPVCC = generate display voltage from 3.3V internally
  if(!display.begin(SSD1306_SWITCHCAPVCC, 0x3C)) { // Address 0x3D for 128x64
    Serial.println(F("SSD1306 allocation failed"));
    for(;;); // Don't proceed, loop forever
  }

  // Show initial display buffer contents on the screen --
  // the library initializes this with an Adafruit splash screen.
  display.display();
  delay(2000); // Pause for 2 seconds

  // Clear the buffer
  display.clearDisplay();
  
}

void loop() {
   // Clear the buffer
  display.clearDisplay();

  drawDvid();
  delay(500);
  blinkCircuit();
  delay(2500);
}


void drawDvid() {
  // Bar width
  int16_t w = 4;
  // Starting point to draw the first D
  int16_t d1_x_pos = 7;
  int16_t d1_y_pos = 17;

  // Starting point to draw the second D
  int16_t d2_x_pos = 78;
  int16_t d2_y_pos = d1_y_pos;

  // Starting point to draw the V
  int16_t v_x_pos = 35;
  int16_t v_y_pos = d1_y_pos;
  int16_t v_slide = 0;
  // Array indicating how frequently to slide V
  int v_blocs_count = 12;
  int v_blocs[v_blocs_count] = {3, 2, 2, 2, 3, 3, 3, 3, 3, 3, 3, 2};
  // y position end
  int16_t text_height = 32;
  int16_t text_y_end = d1_y_pos + text_height;
  
  // Animate the first parts of the D and V
  int16_t i;
  int16_t y;
  int16_t v_cursor = 0;
  int16_t v_count = v_blocs[v_cursor];
  for (i=0; i<text_height+1; i++) {
    y = d1_y_pos + i;
    // Draw first D
    display.drawLine(d1_x_pos, y, d1_x_pos+w, y, WHITE);
    // Draw second D in reverse
    display.drawLine(d2_x_pos, text_y_end-i, d2_x_pos+w, text_y_end-i, WHITE);
    // Draw V
    display.drawLine(v_x_pos+v_slide, y, v_x_pos+v_slide+w, y, WHITE);
    display.display();
    delay(1);

    // Slide V
    v_count--;
    if (v_count == 0) {
      v_slide++;
      v_cursor++;
      v_count = v_blocs[v_cursor];
    }
  }

  // Now draw the horizontal bar of the D
  int16_t d_bar_width = 10;
  
  for (i=0; i<d_bar_width+1; i++) {
    display.drawLine(d1_x_pos+w+1+i, d1_y_pos, d1_x_pos+w+1+i, d1_y_pos+w, WHITE);
    display.drawLine(d2_x_pos+w+1+i, d1_y_pos+text_height-w, d2_x_pos+w+1+i, d1_y_pos+text_height, WHITE);
    display.display();
    delay(2);
  }

  // Draw the vertical bars of the D, the V and the I
  int16_t i_x_pos = 67;
  int16_t d_blocs[] = {1,1,1,1,1,1,1,19,1,1,1,1,1,1,1};
  int16_t d_increment = 1;
  int16_t d_cursor = 0;
  int16_t d_count = d_blocs[d_cursor];
  int16_t d_slide = 0;
  
  d2_x_pos = 90;
  d1_x_pos = 19;
  v_x_pos = 47;
  v_slide = 0;
  v_cursor = v_blocs_count-1;
  v_count = v_blocs[v_cursor];
  for (i=0; i<text_height+1; i++) {
    y =  d1_y_pos + i;
    // draw the V
    display.drawLine(v_x_pos+v_slide, text_y_end-i, v_x_pos+v_slide+w, text_y_end-i, WHITE);
    // draw the I
    display.drawLine(i_x_pos, y, i_x_pos+w, y, WHITE);
    // draw D
    display.drawLine(d2_x_pos+d_slide, text_y_end-i, d2_x_pos+w+d_slide, text_y_end-i, WHITE);
    display.drawLine(d1_x_pos+d_slide, y, d1_x_pos+w+d_slide, y, WHITE);
    display.display();
    delay(1);

    // Slide V
    v_count--;
    if (v_count == 0) {
      v_slide++;
      v_cursor--;
      v_count = v_blocs[v_cursor];
    }

    // Slide D2
    d_count--;
    if (d_count == 0) {
      d_slide = d_slide+d_increment;
      d_cursor++;
      d_count = d_blocs[d_cursor];
      if (d_slide == 7) {
        d_increment = -1;
      }
    }
  }
  
  // Now draw the horizontal bar of the D
  d1_x_pos = d1_x_pos + d_slide -1;
  d2_x_pos = d2_x_pos + d_slide -1;
  for (i=0; i<d_bar_width+1; i++) {
    display.drawLine(d2_x_pos+w+1-i, d1_y_pos, d2_x_pos+w+1-i, d1_y_pos+w, WHITE);
    display.drawLine(d1_x_pos+w+1-i, d1_y_pos+text_height-w, d1_x_pos+w+1-i, d1_y_pos+text_height, WHITE);
    display.display();
    delay(2);
  }
}
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

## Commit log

2019-02-10 version 0.1 gerber + part list
    [Gerber_BoardOutline.GKO, Gerber_BottomLayer.GBL, Gerber_BottomSilkLayer.GBO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]
2019-12-05 add version 1.1 gerberfiles
    [Gerber_BoardOutline.GKO, Gerber_BottomLayer.GBL, Gerber_BottomSilkLayer.GBO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]
2020-11-25 add troubleshooting + datasheet + new test firmware (correcting bugs with new version)
    [testBoard.ino]
2023-10-24 add trace training
